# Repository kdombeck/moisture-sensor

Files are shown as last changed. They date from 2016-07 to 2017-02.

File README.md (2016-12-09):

# Remote moisture sensor
This project will use soil moisture sensors that act like resistors. Readings will be taken at defined intervals and sent to Adafruit.io.

There are 2 main parts to this system the Sensor and Gateway. The sensor will collect the readings from the moisture sensor and send it to the Gateway via [LoRa](https://www.lora-alliance.org/) radio. The Gateway will send the data to [Adafruit.io](https://io.adafruit.com/) via [MQTT](http://mqtt.org/). From there you can create charts and graphs of the data that is being collected.

# Sensor
#### Parts
* [moisture sensor](http://www.irrometer.com/sensors.html#wm) you can have up to 5 per Feather
* [LoRa Feather M0](https://www.adafruit.com/product/3179) or [LoRa Feather 32u4](https://www.adafruit.com/product/3078)
* [GPS Feather wing](https://www.adafruit.com/products/3133) (optional) only works with M0 Feather
  * [antenna](https://www.adafruit.com/products/960)
  * [ufl adapter](https://www.adafruit.com/products/851)
* [OLED display](https://www.adafruit.com/products/2900) (optional)

The moisture sensors act as resistors, so what is shown below are potentiometers in their place. The GPS and OLED display are just stacked on top of the LoRa Feather.

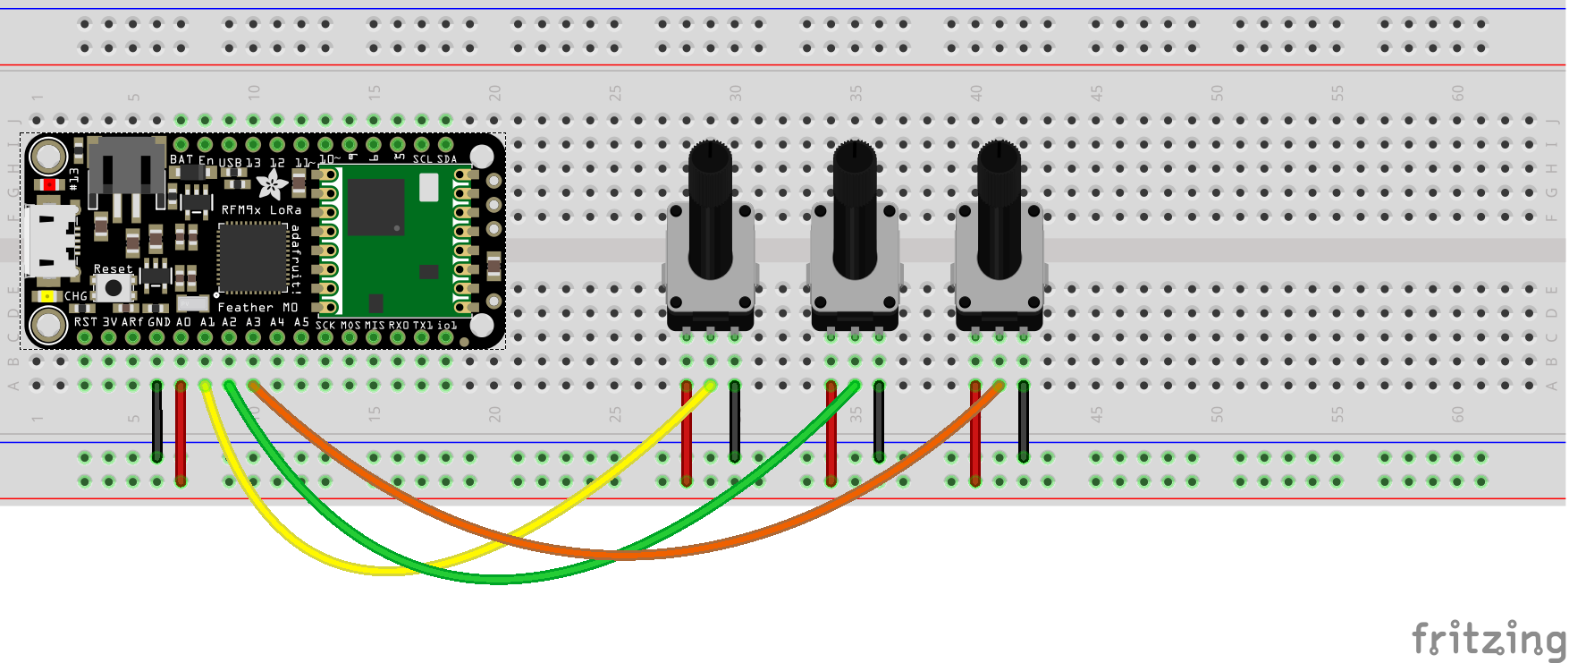
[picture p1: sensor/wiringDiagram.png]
Sensor wiring diagram


You will need to copy [config.h.template](sensor/config.h.template) to config.h and follow the instruction in there on how to create a unique id for each Feather you will be using. This unique id will be part of the MQTT topic so if there are duplicates you will have multiple sensors sending to the same topic and not know which one it came from.

#### Types of messages
###### Sensor data
The analog reading from the sensor will be sent to a topic with the format of station id from config.h and key from data sent. Example: `A-moisture1` will be for station Id `A` and sensor `moisture1`. Battery voltage will also be sent to a topic `A-battery`.

The number of sensors can be adjusted by adding/removing pins from `SENSOR_PINS` in [sensor.ino](sensor/sensor.ino).

Power will only be applied to the sensors while taking a reading via pin `A0`. Constant power to the moisture sensors will cause undo wear.

Example: `A,sensor,moisture1=1.1,moisture2=1.23,moisture3=4.56,battery=3.7`
###### GPS data
GPS data will only be sent when the button is pressed since it is expected that these sensors will not be moving. The GPS data for all Feathers will be sent to a single topic called `gps`. The data value will be the station id. Example: `A`. The latitude, longitude, and elevation will be sent to allow you to map each Feather on a map.

Example: `A,gps,latitude=49.00,longitude=98.00,altitude=200`

# Gateway
#### Parts
* [Wifi Feather M0](https://www.adafruit.com/products/3010)
* [LoRa Wing](https://www.adafruit.com/products/3231) (preferred) or [LoRa breakout](https://www.adafruit.com/products/3072)
* [OLED display](https://www.adafruit.com/products/2900) (optional)

You will need to copy [config.h.template](gateway/config.h.template) to config.h and follow the instruction in there for WIFI and Adafruit.io credentials.

#### LoRa Wing
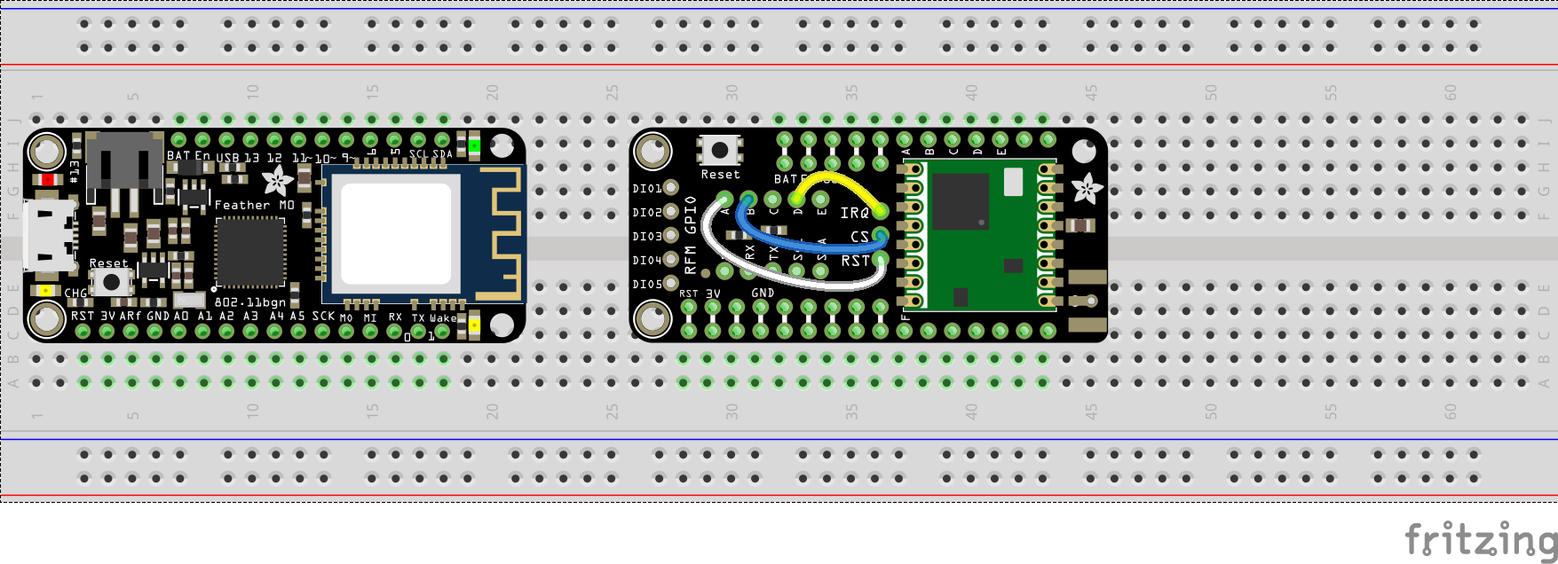
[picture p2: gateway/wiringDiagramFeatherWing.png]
Gateway wiring diagram for feather wing


#### LoRa breakout
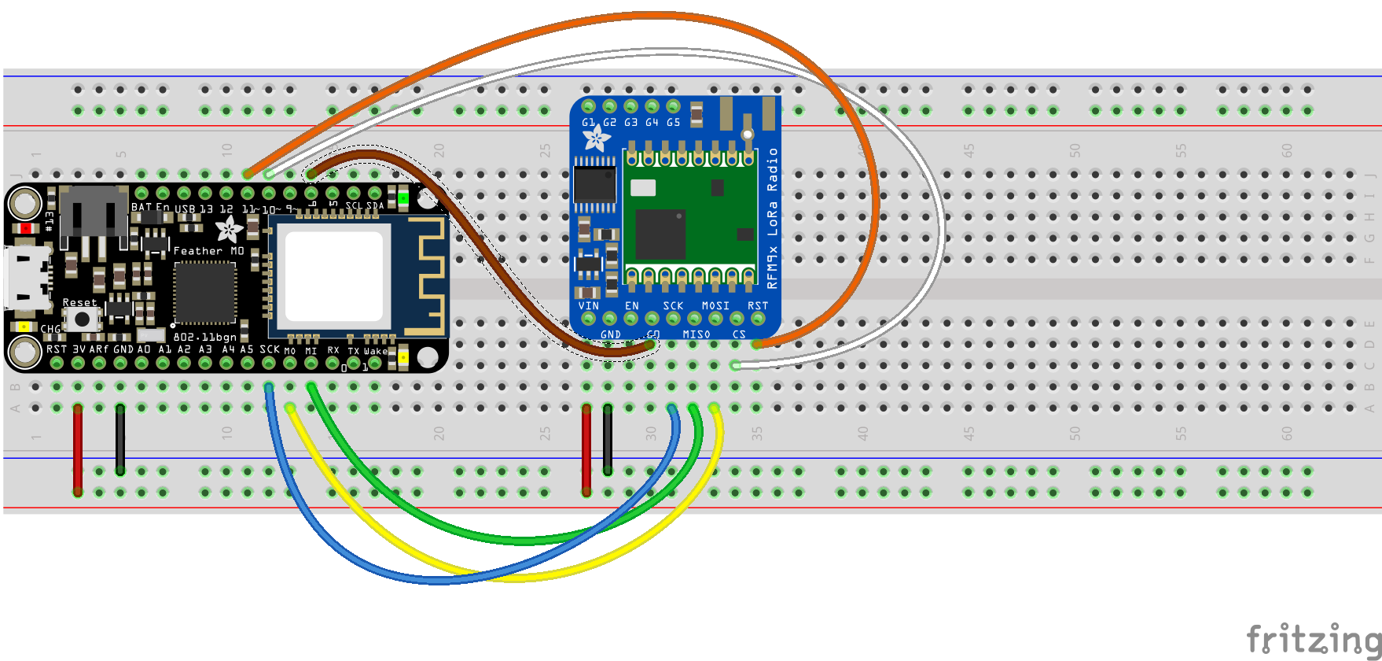
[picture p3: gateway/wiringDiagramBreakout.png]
Gateway wiring diagram for breakout


# Raspberry Pi
With a Raspberry Pi and the code from [here](https://github.com/kdombeck/moisture-sensor/tree/master/raspberrypi) you can create charts like the following. This can be in addition to the functionality provided by Adafruit.io.

#### Parts
* [Raspberry Pi 3](https://www.adafruit.com/products/3055)
* [Power supply](https://www.adafruit.com/products/1995)
* [Micro SD card](https://www.adafruit.com/products/2693)

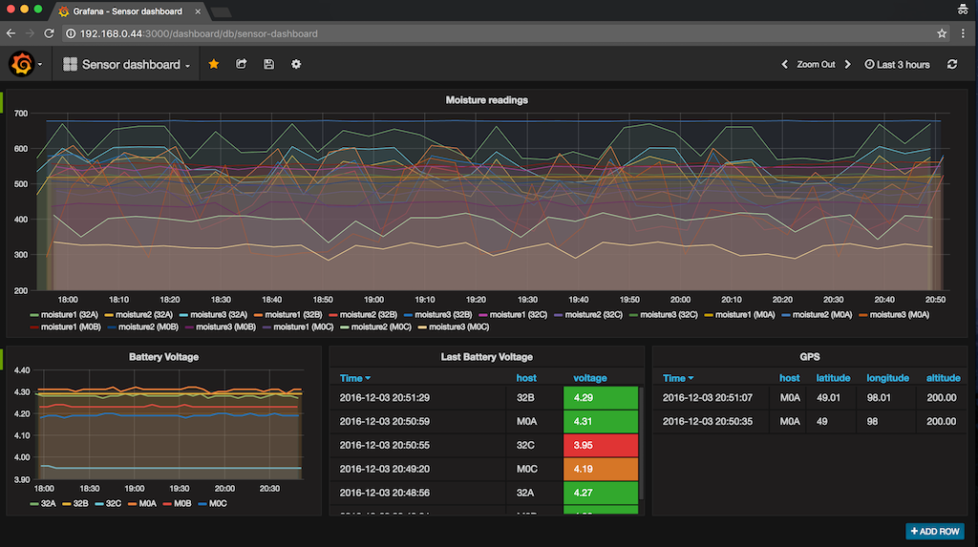
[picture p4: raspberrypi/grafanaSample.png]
Grafana on Raspberry Pi


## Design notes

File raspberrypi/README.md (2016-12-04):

# LoRa data collector
This will take the LoRa sensor data and store it in [InfluxDB](https://www.influxdata.com/time-series-platform/influxdb/) and [Grafana](http://grafana.org/) will be used to graph the data.

#### Installation instructions
* Install [Raspbian Lite](https://www.raspberrypi.org/downloads/raspbian/)
* Execute the following command `curl https://api.github.com/repos/kdombeck/moisture-sensor/releases/latest | grep tarball_url | head -n 1 | cut -d '"' -f 4 | xargs curl -L --output source.tar.gz; rm -rf kdombeck-moisture-sensor-*; tar -xzf source.tar.gz; cd kdombeck-moisture-sensor-*/raspberrypi; sudo ./install.sh`
* Plug [LoRa gateway](https://github.com/kdombeck/moisture-sensor/tree/master/gateway) into Raspberry Pi via USB
* Login into Grafana `http://<raspberrypi ip>:3000/dashboard/db/sensor-dashboard` with username `admin` password `admin`

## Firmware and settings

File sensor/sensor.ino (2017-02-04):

#include <RH_RF95.h>
#include <Adafruit_SleepyDog.h>
#include <Adafruit_GFX.h>
#include <Adafruit_SSD1306.h>
#include "config.h"

// Radio Config
#ifdef ARDUINO_ARCH_SAMD
  #include <Adafruit_GPS.h>

  // for feather m0
  #define RFM95_CS 8
  #define RFM95_RST 4
  #define RFM95_INT 3
  #define VOLTAGE_BATTERY_PIN A7

  // GPS setup
  Adafruit_GPS GPS(&Serial1);
#else
  // for feather32u4
  #define RFM95_CS 8
  #define RFM95_RST 4
  #define RFM95_INT 7
  #define VOLTAGE_BATTERY_PIN A9
#endif

#define RF95_FREQ 915.0

RH_RF95 rf95(RFM95_CS, RFM95_INT);

// Blinky on receipt
#define LED 13

// Oled Config
// buttons a = 9, b = 6, c = 5
#define SEND_DATA_BUTTON_PIN 9
int sendDataLastButtonState = 0;

#define GPS_BUTTON_PIN 6
int gpsLastButtonState = 0;

#define SLEEP_BUTTON_PIN 5
int sleepLastButtonState = 0;

Adafruit_SSD1306 oled = Adafruit_SSD1306();

uint32_t oledRefreshTimer = millis();

// Sensor config
#define SENSOR_POWER_PIN A0
const int SENSOR_PINS[] = {A1, A2, A3};

// Global state
#define DEEP_SLEEP_MILLIS 8000
#define SEND_DATA_INTERVAL_MILLIS 5 * 60000 // 5 minutes

uint32_t sendDataTimer = millis();
uint32_t nbrOfMillisDeepSleeping = 0;
uint32_t nbrOfSentData = 0;
bool deepSleepMode = false;

void setup() {
//  while (!Serial) { delay(10); } // wait for serial connection
  Serial.begin(115200);

  // radio setup
  pinMode(LED, OUTPUT);
  digitalWrite(LED, LOW);
  pinMode(RFM95_RST, OUTPUT);
  digitalWrite(RFM95_RST, HIGH);

  // manual reset
  digitalWrite(RFM95_RST, LOW);
  delay(10);
  digitalWrite(RFM95_RST, HIGH);
  delay(10);

  while (!rf95.init()) {
    Serial.println(F("LoRa radio init failed"));
    while (1);
  }
  Serial.println(F("LoRa radio init OK!"));

  // Defaults after init are 434.0MHz, modulation GFSK_Rb250Fd250, +13dbM
  if (!rf95.setFrequency(RF95_FREQ)) {
    Serial.println(F("setFrequency failed"));
    while (1);
  }
  Serial.print(F("Set Freq to: ")); Serial.println(RF95_FREQ);

  // Defaults after init are 434.0MHz, 13dBm, Bw = 125 kHz, Cr = 4/5, Sf = 128chips/symbol, CRC on

  // The default transmitter power is 13dBm, using PA_BOOST.
  // If you are using RFM95/96/97/98 modules which uses the PA_BOOST transmitter pin, then 
  // you can set transmitter powers from 5 to 23 dBm:
  rf95.setTxPower(23, false);

#ifdef ARDUINO_ARCH_SAMD
  // GPS setup
  // 9600 NMEA is the default baud rate for Adafruit MTK GPS's- some use 4800
  GPS.begin(9600);
  // uncomment this line to turn on RMC (recommended minimum) and GGA (fix data) including altitude
  GPS.sendCommand(PMTK_SET_NMEA_OUTPUT_RMCGGA);
  // uncomment this line to turn on only the "minimum recommended" data
  //GPS.sendCommand(PMTK_SET_NMEA_OUTPUT_RMCONLY);
  // For parsing data, we don't suggest using anything but either RMC only or RMC+GGA since
  // the parser doesn't care about other sentences at this time
  // Set the update rate
  GPS.sendCommand(PMTK_SET_NMEA_UPDATE_1HZ); // 1 Hz update rate
  // For the parsing code to work nicely and have time to sort thru the data, and
  // print it out we don't suggest using anything higher than 1 Hz

  // Request updates on antenna status, comment out to keep quiet
  GPS.sendCommand(PGCMD_ANTENNA);

  // Ask for firmware version
  delay(1000);
  Serial1.println(PMTK_Q_RELEASE);
#endif

  // oled setup
  oled.begin(SSD1306_SWITCHCAPVCC, 0x3C);
  oled.setTextSize(1);
  oled.setTextColor(WHITE);
  oled.clearDisplay();
  oled.setCursor(0,0);
  oled.println(F("A - send sensor data"));
#ifdef ARDUINO_ARCH_SAMD
  oled.println(F("B - send GPS"));
#endif
  oled.println(F("C - deep sleep"));
  oled.display();

  delay(2000);

  pinMode(SENSOR_POWER_PIN, OUTPUT);
  digitalWrite(SENSOR_POWER_PIN, LOW);
  pinMode(SEND_DATA_BUTTON_PIN, INPUT_PULLUP);
  pinMode(GPS_BUTTON_PIN, INPUT_PULLUP);
  pinMode(SLEEP_BUTTON_PIN, INPUT_PULLUP);
}

void loop() {
Serial.println("loop");
  // check to see if sensor data should be sent
  int sendDataButtonState = digitalRead(SEND_DATA_BUTTON_PIN);
  if (sendDataButtonState != sendDataLastButtonState) {
    if (sendDataButtonState == LOW) {
      // if the current state is LOW then the button was pressed
      readAndSendSensorData();
    }
  }

#ifdef ARDUINO_ARCH_SAMD
  // read gps and check to see if the gps should be sent
  if (!deepSleepMode) {
    char c = GPS.read();
    if (GPS.newNMEAreceived()) {
      //Serial.println(GPS.lastNMEA());
      if (GPS.parse(GPS.lastNMEA())) {
        Serial.print(F("Fix: ")); Serial.print((int)GPS.fix); Serial.print(F(" quality: ")); Serial.println((int)GPS.fixquality);
        if (GPS.fix) {
          Serial.print(F("lat ")); Serial.print(GPS.latitudeDegrees, 5); Serial.print(F(" lon ")); Serial.print(GPS.longitudeDegrees, 5);
          Serial.print(F(" Satellites: ")); Serial.println((int)GPS.satellites);
        }
      }
    }
  }
  int gpsButtonState = digitalRead(GPS_BUTTON_PIN);
  if (gpsButtonState != gpsLastButtonState) {
    if (gpsButtonState == LOW) {
      // if the current state is LOW then the button was pressed
      sendGpsData();
    }
  }

  gpsLastButtonState = gpsButtonState;
#endif

  // check to see if the device should be put into deep sleep
  int sleepButtonState = digitalRead(SLEEP_BUTTON_PIN);
  if (sleepButtonState != sleepLastButtonState) {
    if (sleepButtonState == LOW) {
      // if the current state is LOW then the button was pressed
      deepSleepMode = !deepSleepMode;
      nbrOfMillisDeepSleeping = 0;
      Serial.print(F("deep sleep set to ")); Serial.println(deepSleepMode);
    }
  }

  // if millis() or timer wraps around, we'll just reset it
  if (sendDataTimer > millis()) sendDataTimer = millis();

  // automatically send the sensor data based on a time interval
  if (millis() - sendDataTimer > SEND_DATA_INTERVAL_MILLIS ||
      nbrOfMillisDeepSleeping > SEND_DATA_INTERVAL_MILLIS) {
    sendDataTimer = millis(); // reset the timer
    nbrOfMillisDeepSleeping = 0;
    readAndSendSensorData();
  }

  // if millis() or timer wraps around, we'll just reset it
  if (oledRefreshTimer > millis()) oledRefreshTimer = millis();

  // print out the current stats only so often
  // if you print out the stats every time it will not allow the GPS enough time to read the next reading
  if (millis() - oledRefreshTimer > 500 ||
      deepSleepMode) {
    oledRefreshTimer = millis(); // reset the timer
    oled.clearDisplay();
    oled.setCursor(0,0);
    oled.print(F("nbr snt ")); oled.print(nbrOfSentData); oled.print(F(" dsleep ")); oled.println(deepSleepMode);
    oled.print(F("ftr id: ")); oled.print(STATION_ID); oled.print(F(" bat ")); oled.println(readBatteryVoltage());
#ifdef ARDUINO_ARCH_SAMD
    oled.print(F("lt")); oled.print(GPS.latitudeDegrees, 4); oled.print(F(" ln")); oled.println(GPS.longitudeDegrees, 4);
    oled.print(F("fix ")); oled.print(GPS.fix); oled.print(F(" qual ")); oled.print(GPS.fixquality); oled.print(F(" sats ")); oled.println(GPS.satellites);
#endif
    oled.display();
  }

  sendDataLastButtonState = sendDataButtonState;
  sleepLastButtonState = sleepButtonState;

  if (deepSleepMode) {
    // when in deep sleep mode millis() is no longer valid
    // so keep track of the number of deep sleeps for timer intervals
    nbrOfMillisDeepSleeping += Watchdog.sleep(DEEP_SLEEP_MILLIS);
  }
}

void readAndSendSensorData() {
  // turn on the power to the sensors
  digitalWrite(SENSOR_POWER_PIN, HIGH);
  delay(100); // warm them up

  String data = String(STATION_ID);
  data.concat(F(",sensor"));

  // collect and send the data for each one of the sensors
  for (int sensorNbr = 0; sensorNbr < sizeof(SENSOR_PINS) / sizeof(int); sensorNbr++) {
    analogRead(SENSOR_PINS[sensorNbr]); // throw this one away so that we get a good reading on the next one
    data.concat(F(",moisture"));
    data.concat(sensorNbr + 1);
    data.concat(F("="));
    data.concat(analogRead(SENSOR_PINS[sensorNbr]));
  }

  // turn the power off to the sensors to not wear them out
  digitalWrite(SENSOR_POWER_PIN, LOW);

  data.concat(F(",battery="));
  data.concat(readBatteryVoltage());
  sendData(data);
}

float readBatteryVoltage() {
  // same pin is used for A button so delay for a bit to make sure they let go otherwise you will get an invalid reading
  int count = 0;
  int sendDataButtonState = digitalRead(SEND_DATA_BUTTON_PIN);
  while (sendDataButtonState == LOW && count < 50) {
    delay(10);
    count++;
    sendDataButtonState = digitalRead(SEND_DATA_BUTTON_PIN);
  }

  pinMode(SEND_DATA_BUTTON_PIN, INPUT); // sent pin to input otherwise we will not get a valid reading
  analogRead(VOLTAGE_BATTERY_PIN); // throw the first one away
  float measuredvbat = analogRead(VOLTAGE_BATTERY_PIN);
  measuredvbat *= 2;    // we divided by 2, so multiply back
  measuredvbat *= 3.3;  // Multiply by 3.3V, our reference voltage
  measuredvbat /= 1024; // convert to voltage

  // reset the send data pin back to digital so the A button works
  pinMode(SEND_DATA_BUTTON_PIN, INPUT_PULLUP);

  return measuredvbat;
}

#ifdef ARDUINO_ARCH_SAMD
void sendGpsData() {
  if (!GPS.fix) {
    oled.clearDisplay();
    oled.setCursor(0,0);
    oled.println(F("No GPS fix yet"));
    oled.println(F("So not sending"));
    oled.display();
    Serial.println(F("No GPS fix, not sending"));
    delay(2000);
    return;
  }

  char outstr[10];

  String data = String(F(STATION_ID));
  data.concat(F(",gps,latitude="));
  sprintf(outstr, "%f", GPS.latitudeDegrees);
  data.concat(outstr);
  data.concat(F(",longitude="));
  sprintf(outstr, "%f", GPS.longitudeDegrees);
  data.concat(outstr);
  data.concat(F(",altitude="));
  sprintf(outstr, "%f", GPS.altitude);
  data.concat(outstr);

  sendData(data);
}
#endif

void sendData(const String& data) {
  nbrOfSentData++;
  Serial.print(F("Sending ")); Serial.println(data);

  oled.clearDisplay();
  oled.setCursor(0,0);
  oled.print(F("Send ")); oled.println(data);
  oled.display();

  delay(10);
  char dataBuf[data.length() + 1];
  data.toCharArray(dataBuf, data.length() + 1);
  rf95.send((uint8_t *)dataBuf, data.length() + 1);

  oled.println(F("Waiting for response"));
  oled.display();

  Serial.println(F("Waiting to complete"));
  rf95.waitPacketSent();

  // Now wait for a reply
  uint8_t buf[RH_RF95_MAX_MESSAGE_LEN];
  uint8_t len = sizeof(buf);

  Serial.println(F("Waiting for reply"));
  if (rf95.waitAvailableTimeout(2000)) {
    oled.clearDisplay();
    oled.setCursor(0,0);

    // Should be a reply message for us now
    if (rf95.recv(buf, &len)) {
      digitalWrite(LED, HIGH);
      Serial.print(F("Got reply: ")); Serial.println((char*)buf);
      Serial.print(F("RSSI: ")); Serial.println(rf95.lastRssi(), DEC);
      oled.print(F("Reply: ")); oled.println((char*)buf);
      oled.print(F("RSSI: ")); oled.println(rf95.lastRssi(), DEC);
      oled.display();
    } else {
      Serial.println(F("Receive failed"));
      oled.println(F("Receive failed"));
      oled.display();
    }
  } else {
    Serial.println(F("No reply"));
    oled.println(F("No reply"));
    oled.display();
  }

  rf95.sleep();
  digitalWrite(LED, LOW);
  delay(1000);
}

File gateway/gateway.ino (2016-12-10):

#include <SPI.h>
#include <RH_RF95.h>
#include <Adafruit_MQTT.h>
#include <Adafruit_MQTT_Client.h>
#include <WiFi101.h>
#include <Adafruit_GFX.h>
#include <Adafruit_SSD1306.h>
#include "config.h"

// LoRa breakout setup
#define RFM95_CS 10
#define RFM95_RST 11
#define RFM95_INT 6
#define RF95_FREQ 915.0

RH_RF95 rf95(RFM95_CS, RFM95_INT);

// MQTT and WIFI setup
#define WINC_CS   8
#define WINC_IRQ  7
#define WINC_RST  4
#define WINC_EN   2

#define AIO_SERVER      "io.adafruit.com"
#define AIO_SERVERPORT  1883

WiFiClient client;

int status = WL_IDLE_STATUS;

// Store the MQTT server, client ID, username, and password in flash memory.
// This is required for using the Adafruit MQTT library.
const char MQTT_SERVER[] PROGMEM    = AIO_SERVER;
// Set a unique MQTT client ID using the AIO key + the date and time the sketch
// was compiled (so this should be unique across multiple devices for a user,
// alternatively you can manually set this to a GUID or other random value).
const char MQTT_CLIENTID[] PROGMEM  = "WINC1500-client";
const char MQTT_USERNAME[] PROGMEM  = AIO_USERNAME;
const char MQTT_PASSWORD[] PROGMEM  = AIO_KEY;

Adafruit_MQTT_Client mqtt(&client, MQTT_SERVER, AIO_SERVERPORT, MQTT_CLIENTID, MQTT_USERNAME, MQTT_PASSWORD);

// Notice MQTT paths for AIO follow the form: <username>/feeds/<feedname>
const char FEED_NAME_PREFIX[] PROGMEM = AIO_USERNAME "/feeds/";

// Oled Config
Adafruit_SSD1306 oled = Adafruit_SSD1306();

uint32_t oledRefreshTimer = millis();

uint32_t nbrMessagesReceived = 0;
uint32_t nbrMqttSuccessfulSent = 0;
uint32_t nbrMqttFailedToSend = 0;
uint32_t nbrInvalidMessages = 0;

void setup() {
//  while (!Serial) { delay(100); } // wait for serial connection
  Serial.begin(115200);

  Serial.println("LoRa setup");
  pinMode(RFM95_RST, OUTPUT);
  digitalWrite(RFM95_RST, HIGH);

  // manual reset
  digitalWrite(RFM95_RST, LOW);
  delay(10);
  digitalWrite(RFM95_RST, HIGH);
  delay(10);

  while (!rf95.init()) {
    Serial.println("LoRa radio init failed");
    while (1);
  }
  Serial.println("LoRa radio init OK!");

  // Defaults after init are 434.0MHz, modulation GFSK_Rb250Fd250, +13dbM
  if (!rf95.setFrequency(RF95_FREQ)) {
    Serial.println("setFrequency failed");
    while (true);
  }
  Serial.print("Set Freq to: "); Serial.println(RF95_FREQ);

  // Defaults after init are 434.0MHz, 13dBm, Bw = 125 kHz, Cr = 4/5, Sf = 128chips/symbol, CRC on

  // The default transmitter power is 13dBm, using PA_BOOST.
  // If you are using RFM95/96/97/98 modules which uses the PA_BOOST transmitter pin, then 
  // you can set transmitter powers from 5 to 23 dBm:
  rf95.setTxPower(23, false);

  Serial.println("WIFI setup");
  WiFi.setPins(WINC_CS, WINC_IRQ, WINC_RST, WINC_EN);

  // check for the presence of the breakout
  if (WiFi.status() == WL_NO_SHIELD) {
    Serial.println("WINC1500 not present");
    while (true);
  }
  Serial.println("ATWINC OK!");

  // oled setup
  oled.begin(SSD1306_SWITCHCAPVCC, 0x3C);
  oled.setTextSize(1);
  oled.setTextColor(WHITE);
  oled.clearDisplay();
  oled.setCursor(0,0);
  oled.println("LoRa Gateway");
  oled.display();
}

void loop() {
  if (rf95.available()) {
    // Should be a message for us now
    uint8_t buf[RH_RF95_MAX_MESSAGE_LEN];
    uint8_t len = sizeof(buf);

    if (rf95.recv(buf, &len)) {
      nbrMessagesReceived++;
      //RH_RF95::printBuffer("Received: ", buf, len);
      oled.clearDisplay();
      oled.setCursor(0,0);
      oled.print("rvd: "); oled.println((char*)buf);
      oled.display();
      // do NOT change the format of this message since the RaspberryPi depends on it
      Serial.print("Got:  "); Serial.println((char*)buf);
      Serial.print("RSSI: "); Serial.println(rf95.lastRssi(), DEC);

      String message = String((char*)buf);
      processMessage(message);
    } else {
      Serial.println("Receive failed");
    }
  }

  // if millis() or timer wraps around, we'll just reset it
  if (oledRefreshTimer > millis()) oledRefreshTimer = millis();

  // print out the current stats only so often
  if (millis() - oledRefreshTimer > 2000) {
    oledRefreshTimer = millis(); // reset the timer
    oled.clearDisplay();
    oled.setCursor(0,0);
    oled.print("# received    "); oled.println(nbrMessagesReceived);
    oled.print("# MQTT succes "); oled.println(nbrMqttSuccessfulSent);
    oled.print("# MQTT failed "); oled.println(nbrMqttFailedToSend);
    oled.print("# invalid msg "); oled.println(nbrInvalidMessages);
    oled.display();
  }
}

void processMessage(const String& message) {
  if (isValidMessage(message)) {
    int firstCommaPos = message.indexOf(',');
    String stationId = message.substring(0, firstCommaPos);
    int secondCommaPos = message.indexOf(',', firstCommaPos + 1);
    String messageType = message.substring(firstCommaPos + 1, secondCommaPos);

    if (messageType.equals("sensor")) {
      int mqttSuccess = 0;
      int mqttFailure = 0;
      int startPos = secondCommaPos;

      while (startPos > 0) {
        // get key=value pair
        int endPos = message.indexOf(',', startPos + 1);
        if (endPos == -1) {
          endPos = message.length();
        }
        String keyValue = message.substring(startPos + 1, endPos);
        int equalPos = keyValue.indexOf('=');
        String key = keyValue.substring(0, equalPos);
        String value = keyValue.substring(equalPos + 1, keyValue.length());

        String feedName = String(FEED_NAME_PREFIX);
        feedName.concat(stationId);
        feedName.concat("-");
        feedName.concat(key);

        if (sendMqttMessage(feedName, value)) {
          mqttSuccess++;
        } else {
          mqttFailure++;
        }

        // find next comma
        startPos = message.indexOf(',', startPos + 1);
      }

      String reply = String("succ ");
      reply.concat(mqttSuccess);
      reply.concat(" fail ");
      reply.concat(mqttFailure);
      sendLoRaReply(reply);
    } else if (messageType.equals("gps")) {
      String latitude = String();
      String longitude = String();
      String altitude = String();
      int startPos = secondCommaPos;

      while (startPos > 0) {
        // get key=value pair
        int endPos = message.indexOf(',', startPos + 1);
        if (endPos == -1) {
          endPos = message.length();
        }
        String keyValue = message.substring(startPos + 1, endPos);
        int equalPos = keyValue.indexOf('=');
        String key = keyValue.substring(0, equalPos);
        String value = keyValue.substring(equalPos + 1, keyValue.length());

        if (key.equals("latitude")) {
          latitude = value;
        } else if (key.equals("longitude")) {
          longitude = value;
        } else if (key.equals("altitude")) {
          altitude = value;
        } else {
          Serial.print("Unknown key "); Serial.print(key); Serial.print(" value "); Serial.println(value);
        }

        // find next comma
        startPos = message.indexOf(',', startPos + 1);
      }
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

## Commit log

2016-06-22 Transmitter is counting button pushes
2016-06-22 Corrected typo of pin number
2016-06-22 Added sending of the number of button pushes to the receiver
2016-06-23 Added the ability to read an analog sensor on A0
2016-06-24 Added sample app for MQTT for Feather HUZZAH
2016-06-25 Moved "priming" of the pump logic to be closer to where it is used
2016-06-25 When done using the radio put it back to sleep. This changed the constant power draw from 0.026 to 0.015
2016-06-26 Changed variable names of buttons to be the function they perform rather than the physical button name on the oled display since you can configure a button that is not on the oled to do the same thin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
2016-06-26 Print out RSSI after receiving an reply from the receiver
2016-06-28 Removed usage of Adafruit_FeatherOLED_WiFi since it wasn't used and might be conflicting with the GPS wing
2016-07-06 Added GPS collection, not sending it yet. Needed to reduce memory footprint so that it would work on 32u4. It still has memory issues
2016-07-08 Added delay timer when receiving data so that the user can actually see it and not block the radio from receiving other data with a delay.
2016-07-08 Added ability to read multiple sensors. Also only power on the sensor when taking a reading.
2016-07-11 Added sensor number to the messages sent
2016-07-13 LoRa breakout board working with M0 Wifi feather board.
2016-07-16 Added timer to OLED display to only refresh it so often. Otherwise the GPS will not be able to read the data quick enough to allow you to get valid readings
2016-07-16 Send battery voltage to Adafruit.io each time sensor data is collected
2016-07-16 Made constants upper case for consistency
2016-07-16 If the GPS doesn't have a position fix yet don't send it
    [sensor.ino]
2016-07-16 Added timer that will automatically send sensor data
2016-07-16 Added battery voltage to display
2016-07-17 Added better message for when deep sleep button is pressed
2016-07-17 32u4 has a different pin for measuring voltage than the M0
2016-07-17 Make the red LED off by default. Otherwise on the M0 it was on by default.
2016-07-17 First draft of documentation
    [wiringDiagram.fzz]
2016-07-17 When in deep sleep mode the millis() function no longer is valid so we need to use a counter of deep sleeps rather than time interval
    [sensor.ino]
2016-07-17 Comment why time is needed when A button is pressed before getting a battery voltage reading
2016-07-17 Added note about not applying constant power to the sensors
2016-07-17 Added instructions on how to add/remove sensors
2016-07-19 Updated wiring diagram to be a M0 LoRa Feather since it has been published to the Fritzing library
    [wiringDiagram.fzz]
2016-07-19 Corrected variable name that was missed when renaming was done
    [sensor.ino]
2016-07-27 Added debug message letting user know that MQTT failed
    [gateway.ino]
2016-08-01 Added wiring diagram for gateway
    [wiringDiagram.fzz]
2016-08-28 Use hardware SPI rather than software. Hopefully this will improve reliability.
    [wiringDiagram.fzz]
2016-08-28 Changed reset pin to get ready for the LoRa FeatherWing https://learn.adafruit.com/radio-featherwing/wiring so that no code changes are required for it.
    [wiringDiagram.fzz]
2016-09-12 Changed clients to only send 1 message to the gateway for all sensor data (all 3 moisture and battery). This should hopefully reduce client battery usage and gets ready for using data services other 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
2016-09-13 Change GPS message to match new message format like sensor message
2016-09-13 Shorten message so when client sends 1,000+ messages it doesn't wrap
    [sensor.ino]
2016-09-28 Prevent infinite loop trying to connection to MQTT
    [gateway.ino]
2016-11-21 Installation script for storing data on RaspberryPi
2016-11-21 Created service that will insert data from Arduino into InfluxDB via serial cable
2016-11-22 Added systemd setup for sensor service
2016-11-23 Renamed service from sensorservice to loragateway
2016-11-23 If Arduino is not plugged in sleep for a bit before trying again
2016-11-26 Make sure that the user has let go of the A button before taking a battery voltage reading. Otherwise you will get an invalid reading as the A button uses the same pin as the battery voltage reading 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
2016-11-26 Changed timmer to use math to make it easier to change. Can ONLY perform single math operation (NOT 5 * 60 * 1000) otherwise it will not work on 32u4
    [sensor.ino]
2016-11-26 Changed name of panel to mention battery voltage
2016-11-28 Change battery voltage table to only show 1 row per host. Also added coloring to voltage reading so you can easily tell which ones are low.
2016-11-28 Changed Metric and Value column headers to be host and voltage for Last Battery Voltage table
2016-11-30 Use standard WiFi101 library now that Adafruit_WINC1500 is deprecated. Removed unnecessary pin setup.
2016-12-03 Added instructions and diagram for Feather LoRa Wing
    [wiringDiagramBreakout.fzz, wiringDiagramFeatherWing.fzz]
2016-12-04 Initial instructions for Raspberry Pi installation of InfluxDB and Grafana
2016-12-09 Add RaspberryPi parts
2016-12-11 Lowered threshold for load battery indicators
